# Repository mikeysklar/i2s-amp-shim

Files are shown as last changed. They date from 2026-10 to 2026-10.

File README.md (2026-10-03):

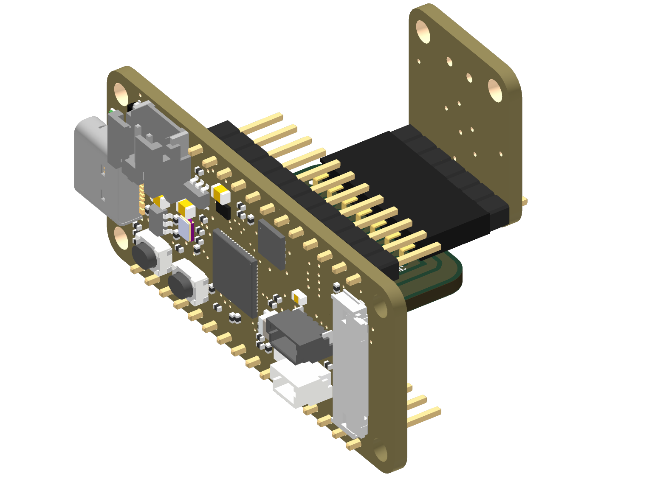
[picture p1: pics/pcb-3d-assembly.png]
KiCad render with a Feather RP2350 and the amp plugged in


# i2s-amp-shim

A direct-connect shim PCB that mates the Adafruit I2S 3W Class D amp breakout (MAX98357A, **#3006**) to a Feather. No breadboard or jumper wires needed.

## About

A passive shim with no components: two right-angle SMD sockets and five traces. The Feather plugs into one edge. The amp plugs into the other edge, standing vertical with its parts facing away from the Feather. Both sockets overhang the board (75% on the Feather side, 61% on the amp side), which keeps the shim to 17.5 × 24.9 mm.

Single copper layer, made for a home build: the outline is milled and the copper is ablated with a fiber laser. Design files are in [`kicad/`](kicad/). The board comes entirely from `kicad/build_pcb.py`.

## Pinout

| Feather | Amp (#3006) | Notes |
|---|---|---|
| 3V | Vin | |
| GND | GND | |
| A0 | BCLK | |
| A1 | LRC | must be the pin after BCLK for RP2xxx PIO I2S |
| A2 | DIN | |
| — | SD | open: amp outputs (L+R)/2 mono |
| — | GAIN | open: 9 dB |

### CircuitPython usage

```python
import audiobusio, board
i2s = audiobusio.I2SOut(bit_clock=board.A0, word_select=board.A1, data=board.A2)
```

## Board notes

- **No crossings.** A0→BCLK and A1→LRC are straight across. A2→DIN runs under the south end of the amp socket and comes into pin 5 from behind.
- **Traces:** 1.0 mm, the full width of the socket pads, with at least 0.6 mm between traces.
- **GND** is a routed trace. The rest of the board is unconnected copper fill with a 0.5 mm gap around every trace and pad, so the laser has less to remove. The fill stays 0.5 mm back from the outline.
- **Front silk:** a label sits past each end of each socket's pin row, where the soldered socket doesn't cover it: 3V and A2 on the Feather side, VIN and LRC on the amp side.
- **Back silk** (burned with the laser): the board name, an A0/A1/A2 → BCLK/LRC/DIN table, and the date.
- **3D view:** the sockets use flat-SMT models made by `kicad/make_3d.py` (FreeCAD) from KiCad's right-angle socket. A Feather RP2350 and the #3006 amp are shown plugged in, using Adafruit's models from [Adafruit_CAD_Parts](https://github.com/adafruit/Adafruit_CAD_Parts). They're board-only, render-only footprints (VIS1, VIS2) with no copper, kept out of the schematic and BOM, and written by `kicad/gen_render_fps.py`.
- **Etch art:** `kicad/etch/etch-FCu-MIRRORED-1to1.pdf` (print at 100%) and `etch-FCu-reference.pdf`.

## Layout

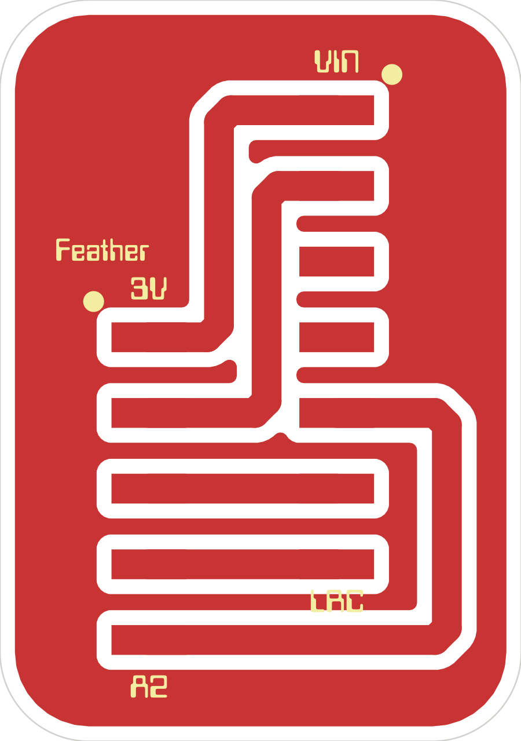
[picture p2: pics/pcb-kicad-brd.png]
PCB layout


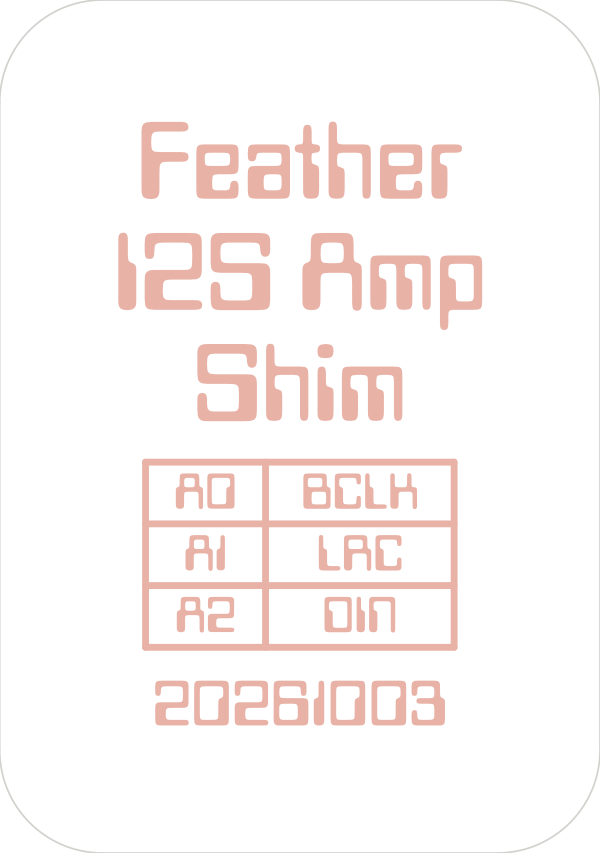
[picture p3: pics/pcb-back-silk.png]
Back silk


## License

[MIT](LICENSE)

The KiCad-derived 3D models in `kicad/3dmodels/` are CC-BY-SA 4.0. The Adafruit board models are MIT, from Adafruit_CAD_Parts.

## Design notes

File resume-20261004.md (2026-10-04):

# Resume: i2s-amp-shim (2026-10-04)

Repo: `/Users/sklarm/Documents/GitHub/i2s-amp-shim` → https://github.com/mikeysklar/i2s-amp-shim (public, MIT).
Last pushed commit: `6fc2ea6` Flat SMT socket models and render-only Feather + amp.
Uncommitted: only `blender/` (user's own, deliberately left untracked and not ignored). This file is uncommitted too.

## What the board is

Passive shim from a Feather's 3V/GND/A0/A1/A2 to the Adafruit MAX98357 I2S amp (#3006).
17.51 × 24.88 mm, single layer F.Cu, no vias, no parts besides the two sockets.

| Feather | Amp | Route |
|---|---|---|
| 3V | Vin (J2.1) | own lane north, east into J2.1 |
| GND | GND (J2.2) | own lane north, east into J2.2 |
| A0 | BCLK (J2.6) | straight |
| A1 | LRC (J2.7) | straight |
| A2 | DIN (J2.5) | east under J2's south end, north under J2 body, west into J2.5 on its row |
| — | SD, GAIN | open (9 dB, (L+R)/2 mono) |

CircuitPython: `audiobusio.I2SOut(bit_clock=board.A0, word_select=board.A1, data=board.A2)`.

## Process and design rules (user's current house style)

- Bantam mills the outline; xTool F1 Ultra fiber laser ablates copper. Bottom silk is burned with the laser.
- Traces 1.0 mm (pad width, "as thick as possible"), ≥0.6 mm between traces, 0.4 mm chamfers, no right angles.
- **No GND pour.** GND is a routed trace. The rest of F.Cu is an **unconnected (no-net) fill**, 0.5 mm gap to all copper, 0.5 min width, inset 0.5 mm from the outline. Fill must form a **closed ring** around the board (XCS trips on open fill) — that's why the east edge was widened.
- Both sockets are right-angle flat SMT, overhanging: J1 75% off the west edge, J2 61% off the east edge.
- Amp plugs in standing vertical, parts facing east (away from Feather), Vin north. Feather stands vertical too, parts facing west, USB end north.
- Front silk: end labels only (past each end of each pin row): `Feather`, `3V`, `A2` at J1; `VIN`, `LRC` at J2; pin-1 dots. 0.8 mm Data 70. Nothing in the strip under the socket legs.
- Back silk (mirrored): "Feather / I2S Amp / Shim", a boxed A0→BCLK / A1→LRC / A2→DIN table, date stamp.
- No mounting holes. Rounded 3 mm corners.

## How to rebuild

From `kicad/`, with KiCad closed (or close without saving first):

```sh
python3 gen_sch.py                                   # schematic (fixed symbol UUIDs)
python3 gen_render_fps.py                            # render-only Feather/amp footprints
/Applications/FreeCAD.app/Contents/Resources/bin/freecadcmd make_3d.py   # flat SMT socket .wrl models
/Applications/KiCad/KiCad.app/Contents/Frameworks/Python.framework/Versions/Current/bin/python3 build_pcb.py
/Applications/KiCad/KiCad.app/Contents/MacOS/kicad-cli pcb drc --severity-all --schematic-parity --format json -o /tmp/drc.json i2s-amp-shim.kicad_pcb
```

Expected DRC: 0 errors, 0 unconnected, 0 parity; one `isolated_copper` warning (the no-net fill, by design) plus TrueType `text_thickness` noise.
`build_pcb.py` also regenerates `etch/etch-FCu-MIRRORED-1to1.pdf` and `etch-FCu-reference.pdf`.
Rebuilding resets any plot settings saved from the KiCad GUI (user had changed DXF units/format/drill shape).

## Files

- `kicad/build_pcb.py` — source of truth for the board. Geometry constants at top, everything derived.
- `kicad/gen_sch.py` — J1 (Conn_01x05_Socket), J2 (Conn_01x07_Socket); nets /3V3 /GND /BCLK /LRC /DIN.
- `kicad/footprints/i2s-amp-shim.pretty/` — `Feather_RtAngle_Socket_SMD_1x05`, `Amp_RtAngle_Socket_SMD_1x07` (pads copied from sdio-shim's `header-rt-ang-smd`: 2.51 × 1.0 at x=±6.7), and render-only `Render_Feather_RP2350_on_J1`, `Render_MAX98357_on_J2` (board_only, excluded from BOM/pos, no pads; placed as VIS1/VIS2 at the J1/J2 origins).
- `kicad/make_3d.py` — FreeCAD: stock THT right-angle socket → body kept, legs cut at board surface, flat feet added → VRML (black body, gold pins; STEP from freecadcmd loses colours).
- `kicad/gen_render_fps.py` — computes KiCad model offset/rotate for Adafruit boards + male headers. KiCad applies `Rz(-rz)·Ry(-ry)·Rx(-rx)`; decomposition handles gimbal lock (the headers hit it).
- `kicad/3dmodels/` — Adafruit STEPs (MIT, Adafruit_CAD_Parts), KiCad header/socket STEPs (CC-BY-SA), generated `.wrl`.

## Verified facts (don't re-derive)

- #3006 JP1 (Adafruit EAGLE): 1=Vin 2=GND 3=SD 4=GAIN 5=DIN 6=BCLK 7=LRC.
- Feather RP2350 JP1 (16-pin, EAGLE): from the USB end RESET, 3.3V, 3.3V, GND, A0, A1, A2, A3, D24, D25, SCK, MOSI, MISO, RX, TX, PSRAM_CS. No AREF, so 3V and GND are adjacent. J1 mates the second 3.3V through A2.
- No flat-SMT right-angle socket model existed locally (user's `~/Documents/KiCad/9.0/footprints/header-rt-ang-smd` and `rt-ang` have no model) or in KiCad stock; hence `make_3d.py`.

## Open / next

- Laser workflow: DXF of B.SilkS comes out mirrored (KiCad plots from the top; `kicad-cli pcb export dxf` has no mirror). Current answer: reflect in XCS with the outline selected, matching how the board is flipped on the bed. Offered, not done: add a pre-mirrored `etch/silk-BACK-for-laser.svg` (B.SilkS + Edge.Cuts, `kicad-cli pcb export svg --mirror`) to `build_pcb.py`.
- Amp 3D model has no speaker terminal block.
- Not yet fabricated or test-fit. Physical checks once cut: Feather/amp seat in the right-angle sockets, DIN clearance under J2 body, fill ring burns cleanly.
- Possible README/guide follow-up: photos once built (`pics/`).

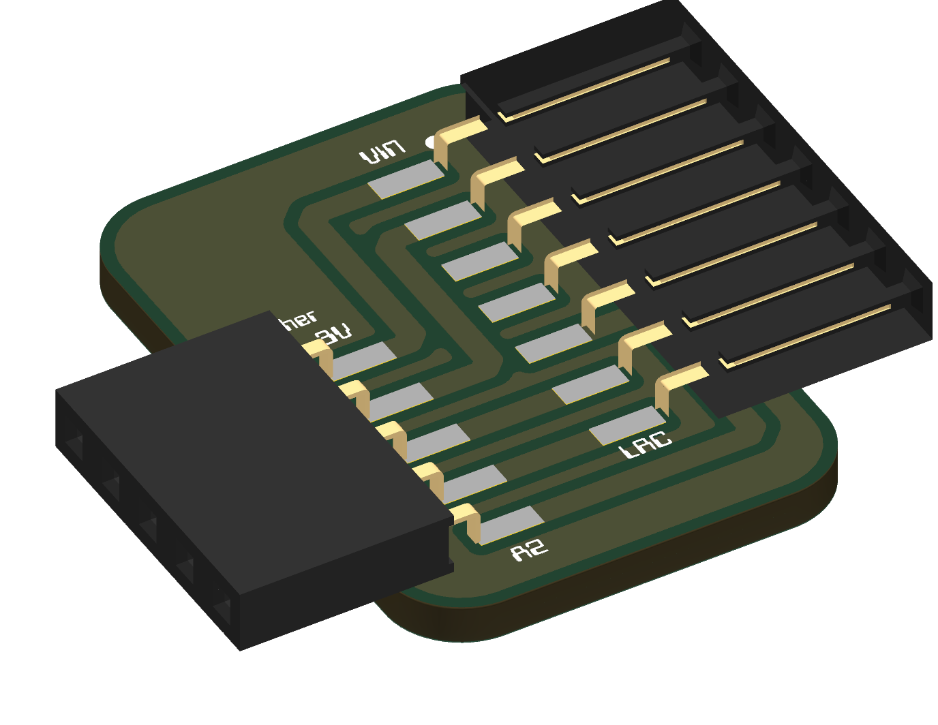
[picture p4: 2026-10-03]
pics/pcb-3d.png

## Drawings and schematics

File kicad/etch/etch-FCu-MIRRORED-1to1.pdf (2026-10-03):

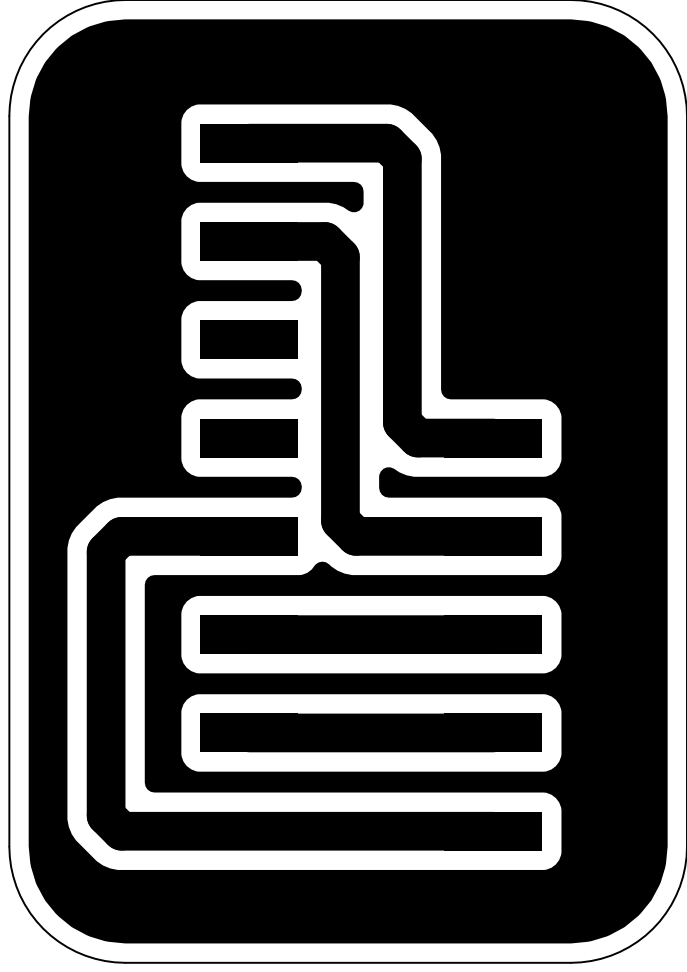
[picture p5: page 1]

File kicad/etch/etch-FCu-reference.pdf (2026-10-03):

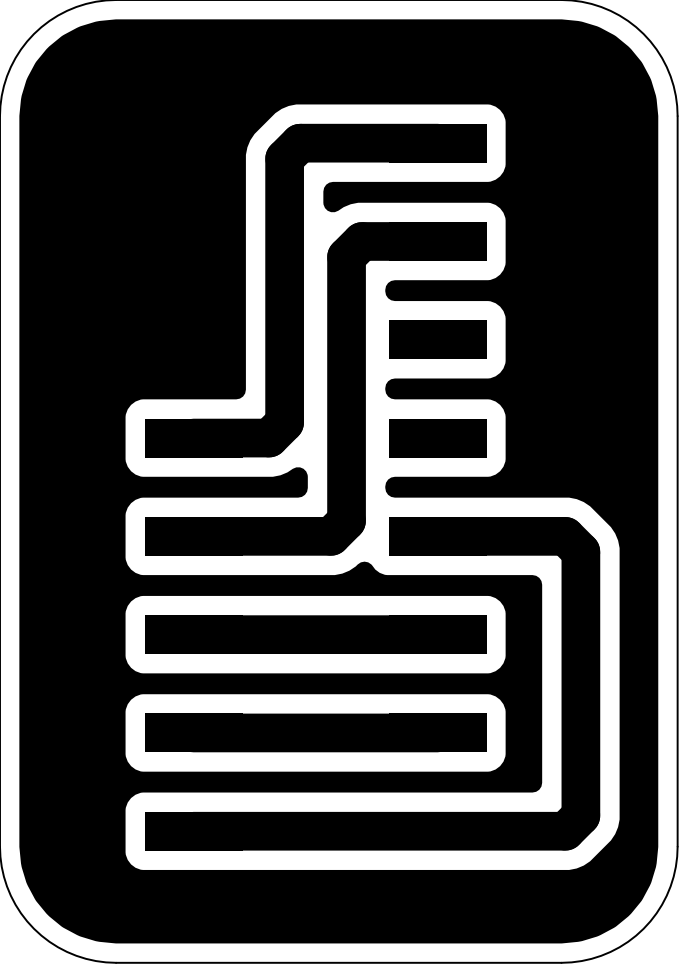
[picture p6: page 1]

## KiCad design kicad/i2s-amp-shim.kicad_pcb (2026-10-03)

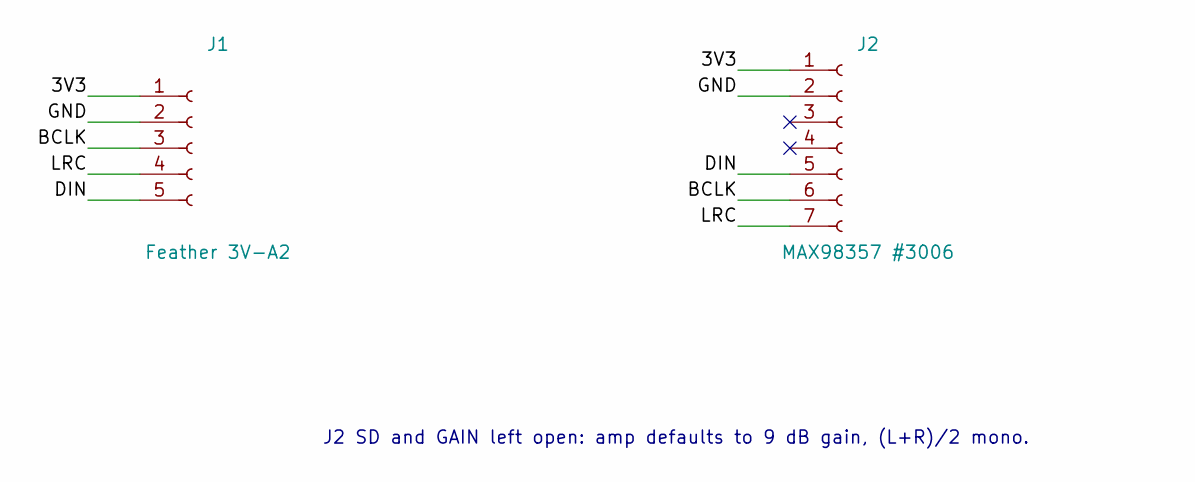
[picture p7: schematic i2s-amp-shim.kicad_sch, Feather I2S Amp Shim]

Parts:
J1: Feather 3V-A2; Feather_RtAngle_Socket_SMD_1x05
J2: MAX98357 #3006; Amp_RtAngle_Socket_SMD_1x07

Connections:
/3V3: J1.1, J2.1
/BCLK: J1.3, J2.6
/DIN: J1.5, J2.5
/GND: J1.2, J2.2
/LRC: J1.4, J2.7

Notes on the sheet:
J2 SD and GAIN left open: amp defaults to 9 dB gain, (L+R)/2 mono.

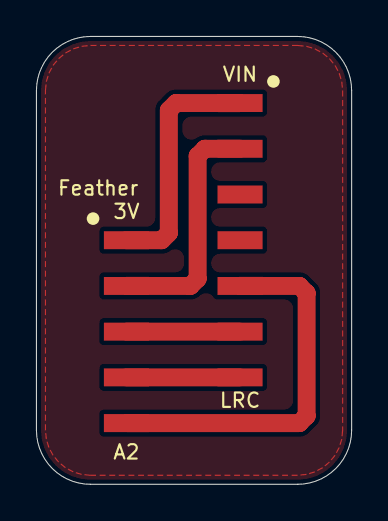
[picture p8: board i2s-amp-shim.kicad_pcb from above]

Board: 2 copper layers, 17.5 x 24.9 mm, 4 parts (0 on the bottom side), 5 nets.

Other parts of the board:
VIS1: Render_Feather_RP2350_on_J1
VIS2: Render_MAX98357_on_J2

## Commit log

2026-10-03 Feather I2S amp shim: KiCad design, etch art, renders
    Single-sided shim that mates a Feather's 3V/GND/A0/A1/A2 to the
    Adafruit MAX98357 I2S amp (#3006) through two right-angle SMD sockets.
    No crossings or jumpers, 1.0mm traces, unconnected copper fill closed
    around the board for the laser, name and pin table on the back silk.
    Board is generated by kicad/build_pcb.py; schematic by kicad/gen_sch.py.
    [i2s-amp-shim.kicad_pcb, i2s-amp-shim.kicad_sch]
2026-10-03 Flat SMT socket models and render-only Feather + amp
    Sockets now use flat-SMT right-angle models (make_3d.py, FreeCAD) instead
    of KiCad's through-hole part. Add board-only, render-only footprints that
    show an Adafruit Feather RP2350 and the MAX98357 (#3006) plugged into J1
    and J2, using Adafruit_CAD_Parts models plus KiCad male headers. No copper
    or schematic change. Ignore KiCad plot outputs and local history.
    [i2s-amp-shim.kicad_pcb]
2026-10-15 README: animated hero of the shim stack-up
    Isometric figure of the Feather and MAX98357 in the shim's sockets,
    lighting each net in turn and coming apart. The KiCad render moves
    to the Layout section.
2026-10-15 README: add build photos
    Laser-ablated copper, solder mask with pads opened, and the
    assembled stack next to its paste stencil.
2026-10-15 Mention the solder mask step
    The board gets solder mask after laser ablation. Say so in the README
    and drop the stale "no mask" from the GAP comment in build_pcb.py.
